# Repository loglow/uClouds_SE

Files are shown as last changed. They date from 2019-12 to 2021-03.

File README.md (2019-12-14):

# µClouds SE (uClouds, microClouds) Eurorack [Rev D]

## 8HP Eurorack module | Granular audio processor

[μClouds SE](http://uclouds-se.com) is a granular audio processor that creates textures and soundscapes by combining multiple segments of sound taken from a recording buffer.

This re-engineered Eurorack module updates and simplifies the classic [Mutable Instruments Clouds](https://mutable-instruments.net/modules/clouds/) design by miniaturizing the module from 18HP to 8HP and redesigning the front panel layout without eliminating any original functionality.

Fully compatible with upstream Clouds firmware. Includes power cable, mounting hardware, and a one-year warranty. Designed and built with care by [Tall Dog Electronics](http://tall-dog.com) in Western Massachusetts. Licensed [CC BY-SA 4.0](https://creativecommons.org/licenses/by-sa/4.0/) open source hardware.

- **Height:** 3U (128.5 mm)
- **Width:** 8HP (40.3 mm)
- **Depth:** 43 mm (with power)
- **+12V:** 120 mA (average)
- **-12V:** 10 mA (average)

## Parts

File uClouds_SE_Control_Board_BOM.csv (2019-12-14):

Reference | Quantity | Description | Manufacturer | Part Number | Digi-Key P/N
D1 D2 D3 D4 | 4 | LED GRN/RED DIFF 3MM ROUND T/H | Kingbright | WP3VEGW | 754-1221-ND
DS1 DS2 DS3 DS4 | 4 | LED SPACER 3MM T-1 BLACK 8MM | Essentra | LEDM-2-08 | RPC4261-ND
H1 H2 H3 H4 | 4 | CONN HEADER 10POS .100 STR 15AU | Amphenol FCI | 67997-210HLF | 609-3236-ND
J1 J2 J3 J4 J5 J6 J7 J8 J9 J10 J11 J12 | 12 | 3.5MM JACK VERTICAL PCB MOUNT | Wenzhou QingPu | WQP-PJ398SM | N/A
P1 P2 P4 P5 P6 P7 | 6 | POT 9MM LINEAR B10K | Song Huei | R0904N-B10K,L-25KQ/LWS | N/A
P3 | 1 | POT 9MM AUDIO A50K DUAL GANG | Song Huei | RK1109G-A50K,L-25KC | N/A
S1 | 1 | SWITCH TACTILE SPST-NO 0.05A 12V | E-Switch | TL1265GQSCLR | EG4967-ND
S2 S3 | 2 | SWITCH TACTILE SPST-NO 0.05A 12V | E-Switch | TL1105DF160Q | EG1865-ND

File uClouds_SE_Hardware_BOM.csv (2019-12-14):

Description | Quantity
Button Shim, FR-4, Black, 1.2 mm | 1
Micro Knob, T18 Shaft, Black | 1
Thonkiconn Knurled Nut, Steel, M6 | 12
Threaded Hex Standoff, Brass, M2.5 x 11 mm | 2
Standoff Screw, Button Head, Hex Socket, M2.5 x 6 mm | 4

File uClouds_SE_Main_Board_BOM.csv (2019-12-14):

Reference | Quantity | Description | Manufacturer | Part Number | Digi-Key P/N
C1 C7 C9 C11 C13 C14 C17 C18 C19 C20 C24 C32 C33 C34 C35 C36 C47 C49 C50 C53 C55 | 21 | CAP CER 0.1UF 16V X7R 0603 | Samsung | CL10B104KO8NNWC | 1276-1939-1-ND
C2 C4 C15 C21 C26 C27 C41 C42 C43 | 9 | CAP 10 UF 20% 25 V | Wurth Electronics | 865230440002 | 732-8259-1-ND
C3 C6 C16 C25 | 4 | CAP CER 1UF 16V X7R 0603 | Samsung | CL10B105MO8NNWC | 1276-6524-1-ND
C5 C10 | 2 | CAP CER 2.2UF 10V X7R 0603 | Samsung | CL10B225KP8NNNC | 1276-1134-1-ND
C8 C12 C22 C23 C28 C37 | 6 | CAP CER 18PF 50V C0G/NP0 0603 | Samsung | CL10C180FB8NNNC | 1276-2206-1-ND
C29 C30 C31 C38 C39 C40 | 6 | CAP CER 1000PF 50V C0G/NP0 0603 | Samsung | CL10C102JB8NNNC | 1276-1091-1-ND
C44 C48 C51 C52 C54 | 5 | CAP 47 UF 20% 25 V | Wurth Electronics | 865230445005 | 732-8262-1-ND
C45 C46 | 2 | CAP CER 220PF 50V C0G/NP0 0603 | Samsung | CL10C221JB8NNNC | 1276-1048-1-ND
D1 D2 | 2 | DIODE SCHOTTKY 40V 1A SOD123 | Diodes Incorporated | 1N5819HW-7-F | 1N5819HW-FDICT-ND
H1 H2 H3 H4 | 4 | CONN HEADER FMAL 10PS.1" DL GOLD | Sullins | PPPC052LFBN-RC | S7108-ND
H5 | 1 | BOX HEADER, 0.050 10 POS | CNC Tech | 3220-10-0100-00 | 1175-1627-ND
H7 | 1 | CONN HEADER VERT 10POS GOLD | On Shore Technology | 302-S101 | ED1543-ND
Q1 Q2 | 2 | TRANS NPN 40V 0.2A SMD SOT23-3 | Diodes Incorporated | MMBT3904-7-F | MMBT3904-FDICT-ND
R1 R13 R21 | 3 | RES SMD 10K OHM 1% 1/10W 0603 | Panasonic | ERJ-3EKF1002V | P10.0KHCT-ND
R2 R3 | 2 | RES SMD 100 OHM 1% 1/10W 0603 | Panasonic | ERJ-3EKF1000V | P100HCT-ND
R4 R5 | 2 | RES SMD 2.2K OHM 1% 1/10W 0603 | Panasonic | ERJ-3EKF2201V | P2.20KHCT-ND
R6 R7 R8 R12 R20 R42 R43 R44 | 8 | RES SMD 100K OHM 0.1% 1/10W 0603 | Susumu | RG1608P-104-B-T5 | RG16P100KBCT-ND
R9 R11 R32 R33 R34 | 5 | RES SMD 200K OHM 0.1% 1/10W 0603 | Susumu | RG1608P-204-B-T5 | RG16P200KBCT-ND
R10 | 1 | RES SMD 180K OHM 0.1% 1/10W 0603 | Susumu | RG1608P-184-B-T5 | RG16P180KBCT-ND
R14 R28 R29 | 3 | RES SMD 33K OHM 0.1% 1/10W 0603 | Susumu | RG1608P-333-B-T5 | RG16P33.0KBCT-ND
R15 | 1 | RES SMD 47K OHM 0.1% 1/10W 0603 | Susumu | RG1608P-473-B-T5 | RG16P47.0KBCT-ND
R16 R30 | 2 | RES SMD 66.5KOHM 0.1% 1/10W 0603 | Panasonic | ERA-3AEB6652V | P66.5KDBCT-ND
R17 R26 R46 R47 R48 R49 | 6 | RES SMD 5.6K OHM 0.1% 1/10W 0603 | Susumu | RG1608P-562-B-T5 | RG16P5.6KBCT-ND
R18 R19 R25 R27 | 4 | RES SMD 39K OHM 0.1% 1/10W 0603 | Susumu | RG1608P-393-B-T5 | RG16P39.0KBCT-ND
R22 R23 | 2 | RES SMD 1K OHM 0.1% 1/10W 0603 | Susumu | RG1608P-102-B-T5 | RG16P1.0KBCT-ND
R24 R35 R36 R37 R38 R39 R40 R41 | 8 | RES SMD 68 OHM 1% 1/10W 0603 | Panasonic | ERJ-3EKF68R0V | P68.0HCT-ND
R31 R54 | 2 | RES SMD 470 OHM 1% 1/10W 0603 | Panasonic | ERJ-3EKF4700V | P470HCT-ND
R45 | 1 | RES SMD 4.7 OHM 5% 1/4W 1206 | Panasonic | ERJ-8GEYJ4R7V | P4.7ECT-ND
R50 R53 | 2 | RES SMD 22K OHM 0.1% 1/10W 0603 | Susumu | RG1608P-223-B-T5 | RG16P22.0KBCT-ND
R51 R52 | 2 | RES SMD 3.3K OHM 0.1% 1/10W 0603 | Susumu | RG1608P-332-B-T5 | RG16P3.3KBCT-ND
U1 | 1 | IC CODEC PORT INTERNET 28SSOP | Cirrus Logic | WM8731SEDS/RV | WM8731SEDS/RVCT-ND
U2 | 1 | IC MCU 32BIT 1MB FLASH 64LQFP | STMicroelectronics | STM32F405RGT6 | 497-11767-ND
U3 U7 | 2 | IC OPAMP JFET 3MHZ 8TSSOP | Texas Instruments | TL072CPWR | 296-7193-1-ND
U4 | 1 | IC OPAMP GP 1MHZ RRO 14TSSOP | Microchip Technology | MCP6004T-E/ST | MCP6004T-E/STCT-ND
U5 | 1 | IC OPAMP GP 1MHZ RRO 8MSOP | Microchip Technology | MCP6002T-I/MS | MCP6002T-I/MSCT-ND
U6 | 1 | IC 8BIT SHIFT REGISTER 16-TSSOP | Texas Instruments | SN74HC595PWR | 296-23258-1-ND
U8 U9 | 2 | IC REG LINEAR 3.3V 800MA SOT223 | Texas Instruments | LM1117IMP-3.3/NOPB | LM1117IMP-3.3/NOPBCT-ND
U10 | 1 | IC VREF SHUNT 10V SOT23-3 | Texas Instruments | LM4040C10IDBZR | 296-20882-1-ND
X1 | 1 | CRYSTAL 12.2880MHZ 18PF SMD | Abracon | ABM3-12.288MHZ-D2Y-T | 535-10635-1-ND
X2 | 1 | CRYSTAL 8.0000MHZ 18PF SMD | Abracon | ABM3-8.000MHZ-D2Y-T | 535-10630-1-ND

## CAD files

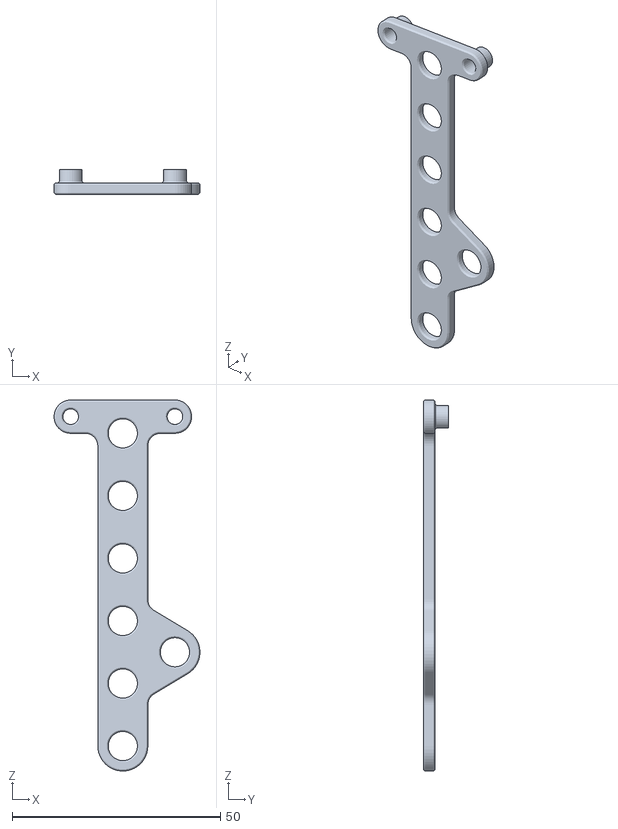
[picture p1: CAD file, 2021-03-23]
uClouds_SE_Assembly_Spacer.stl
35.0 x 6.00 x 89.0

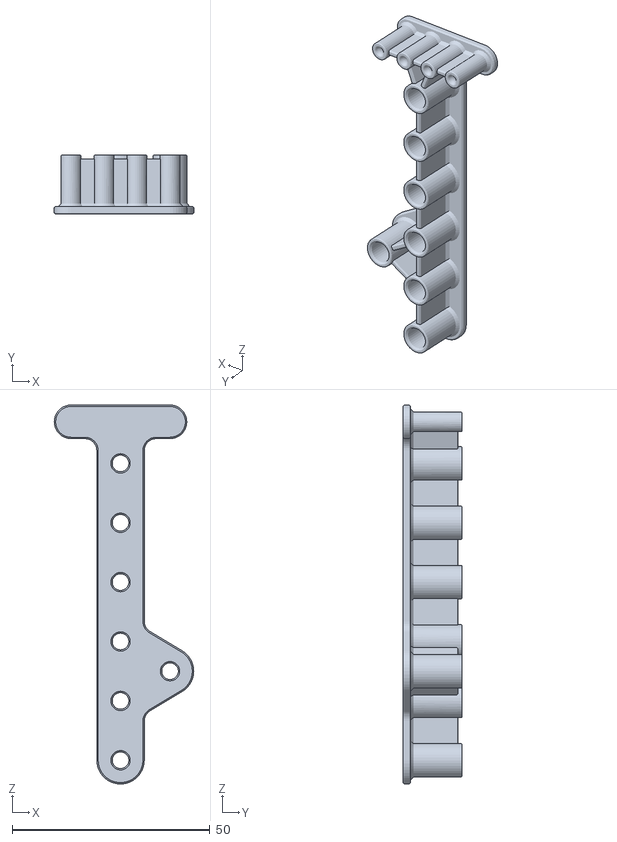
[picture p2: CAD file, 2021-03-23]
uClouds_SE_Assembly_Cap.stl
35.2 x 15.0 x 95.8

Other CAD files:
uClouds_SE_Model.skp

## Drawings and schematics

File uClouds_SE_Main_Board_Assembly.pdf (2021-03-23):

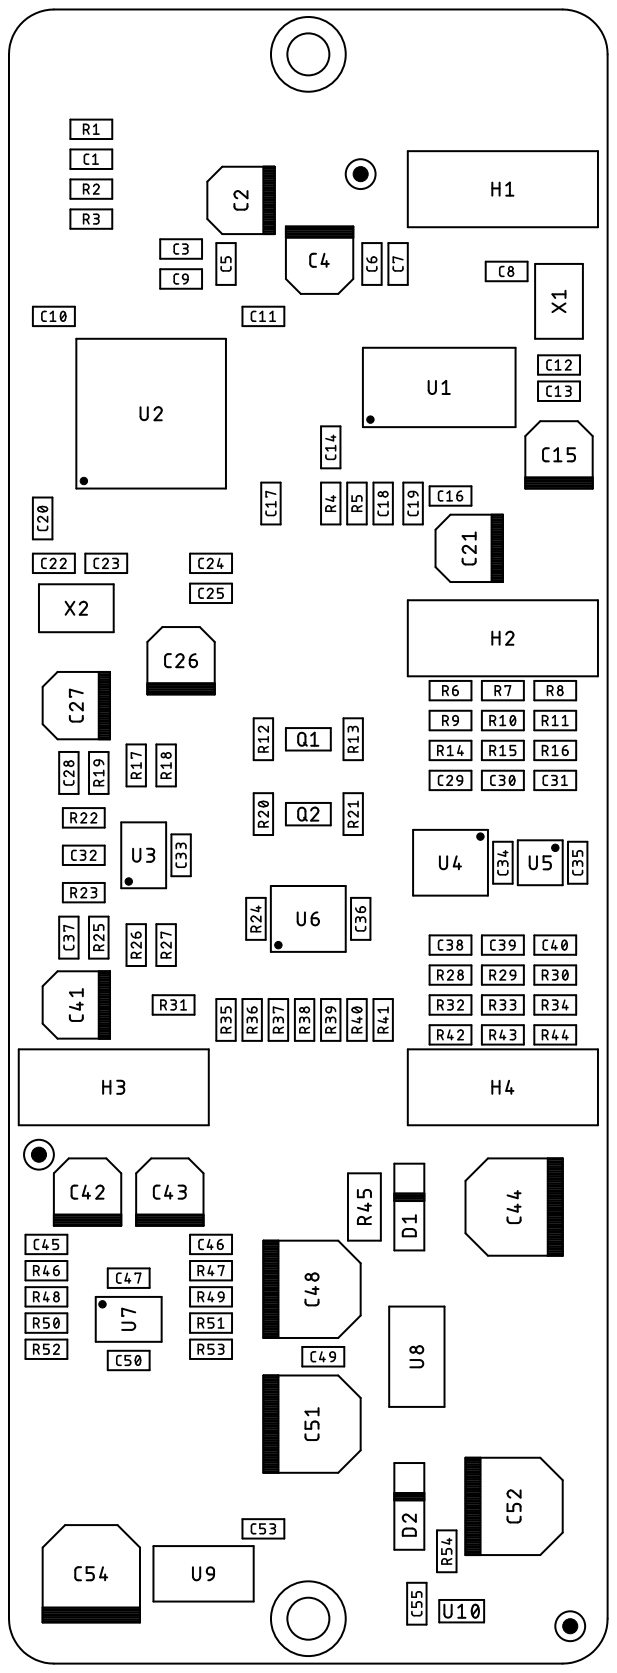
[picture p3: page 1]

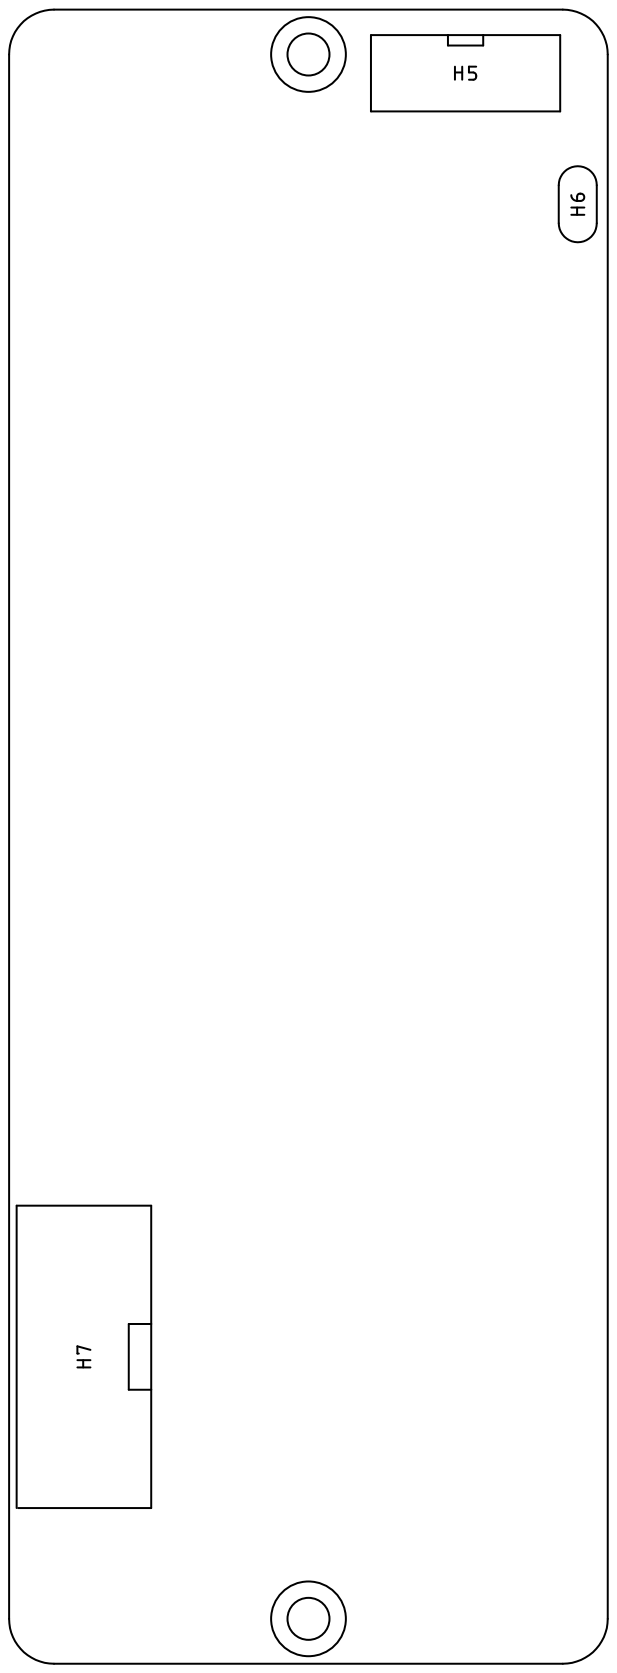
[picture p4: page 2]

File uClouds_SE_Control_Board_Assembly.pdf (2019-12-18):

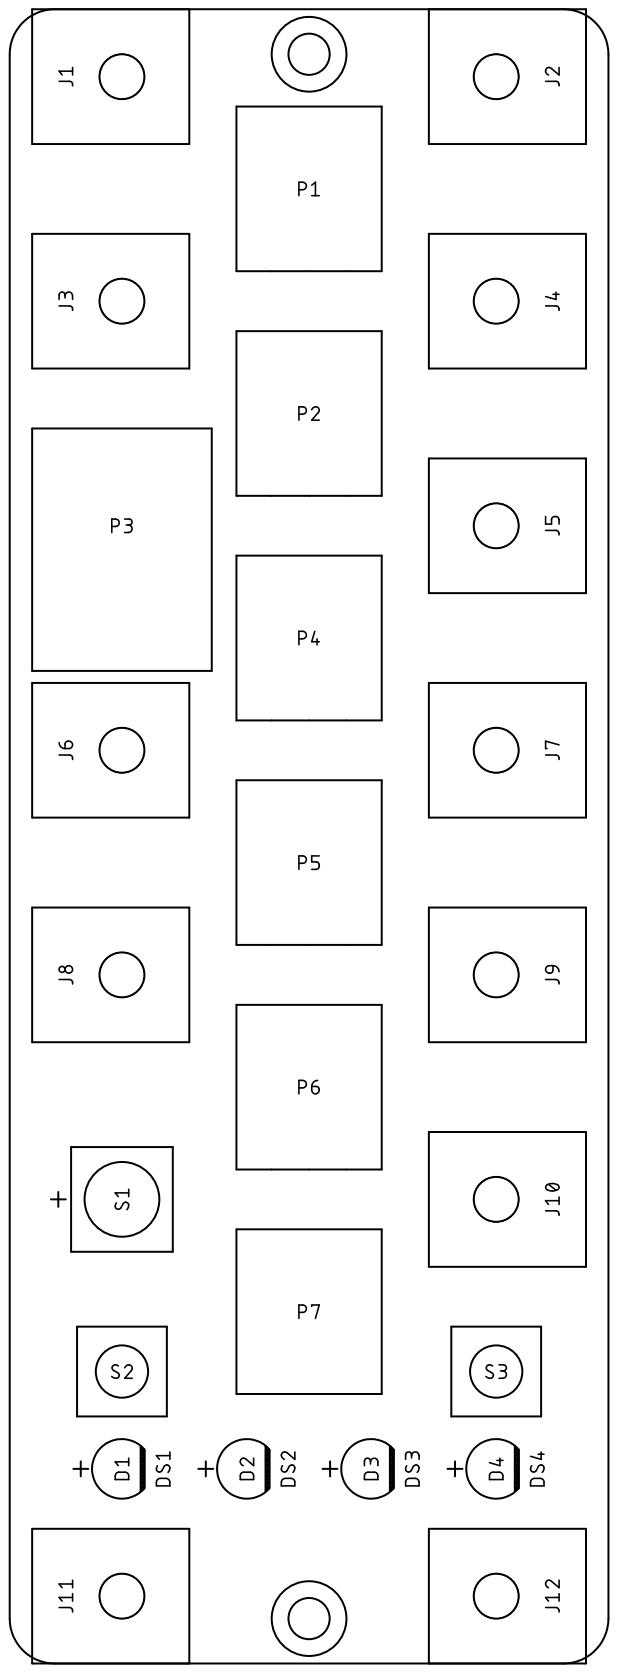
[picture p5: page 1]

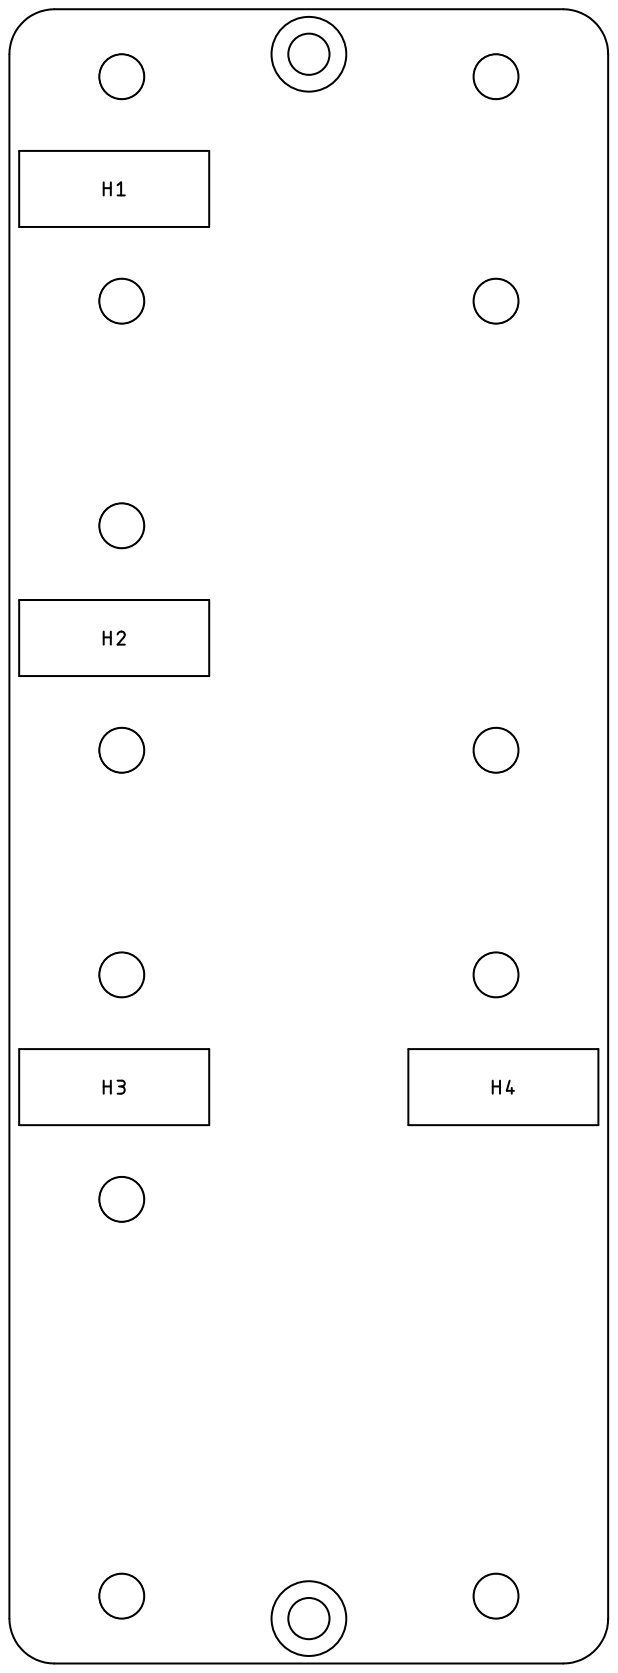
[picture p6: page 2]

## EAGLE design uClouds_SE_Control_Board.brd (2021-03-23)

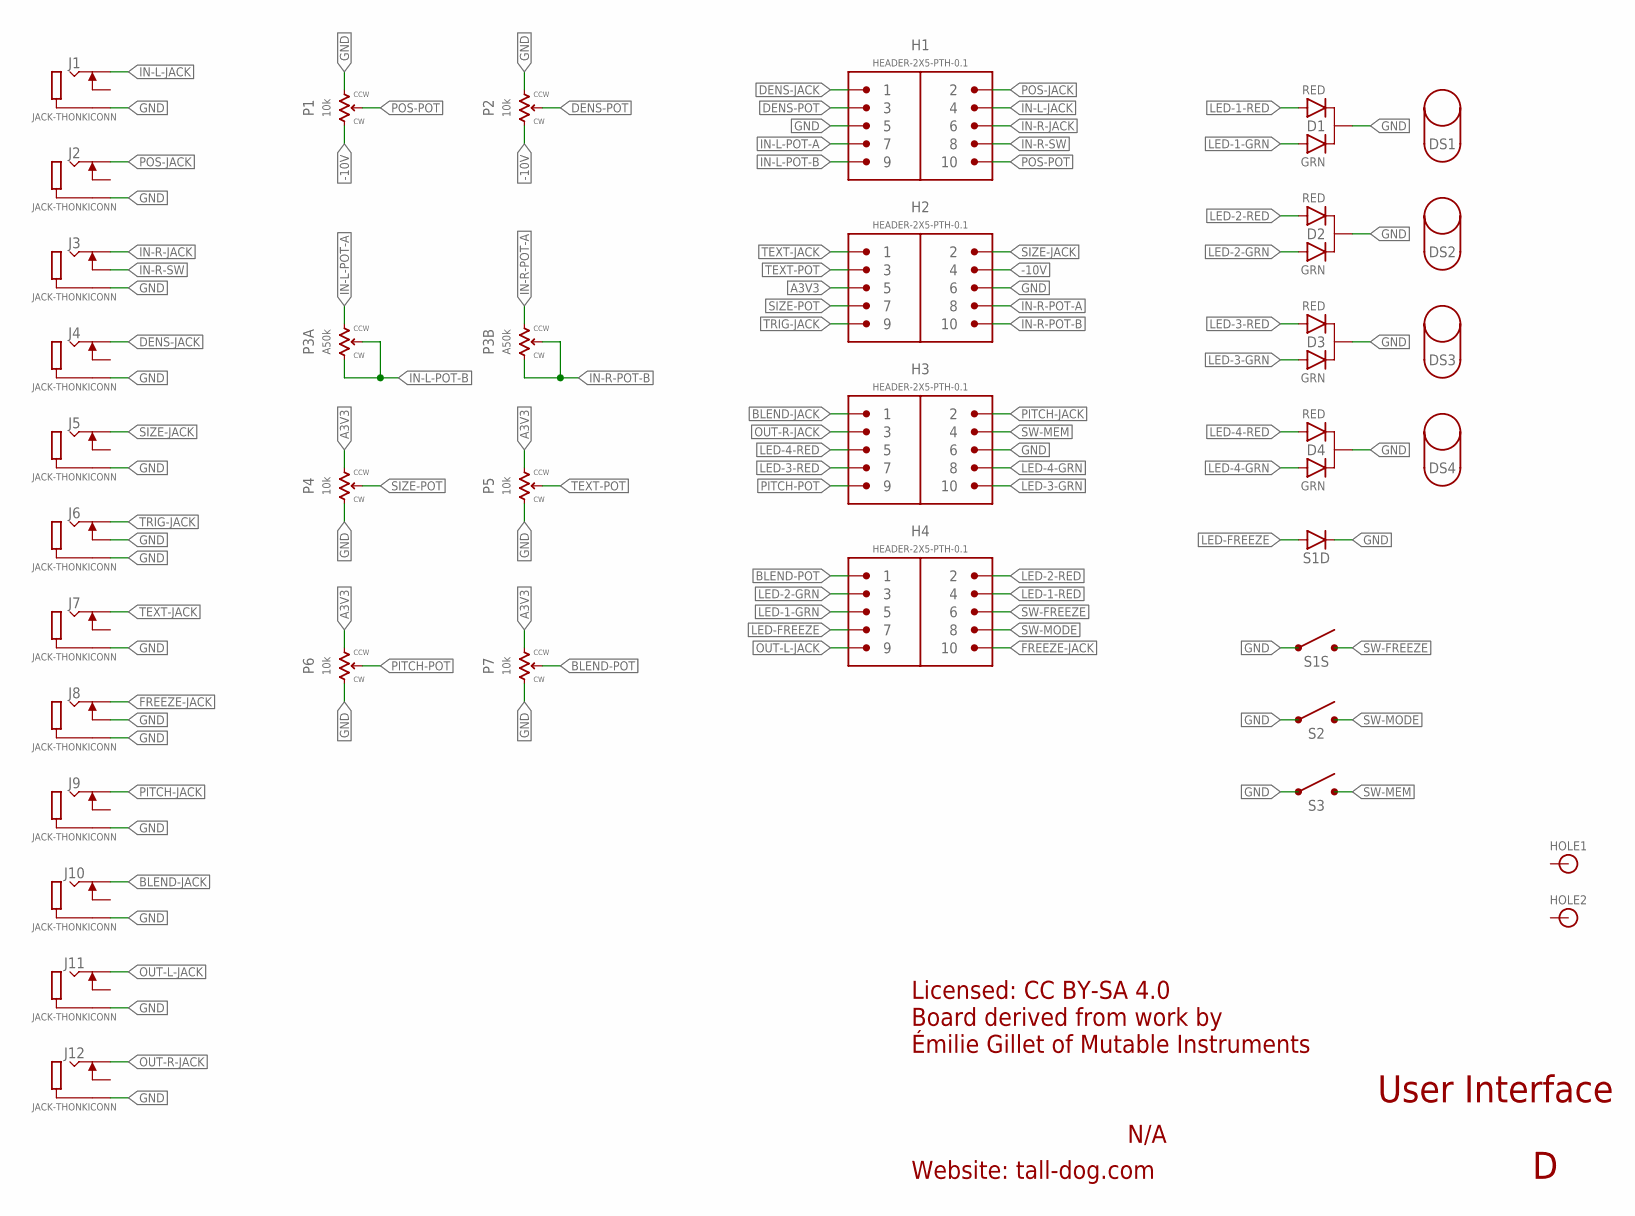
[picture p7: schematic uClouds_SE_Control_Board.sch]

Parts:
D1, D2, D3, D4: LED-DUAL-PTH; LED-T1-3
DS1, DS2, DS3, DS4: LED-SPACER
H1, H2, H3, H4: HEADER-2X5-PTH-0.1; PTH-0.1-2X5-MALE
HOLE1, HOLE2: HOLE; M2.5-HOLE
J1, J2, J3, J4, J5, J6, J7, J8, J9, J10, J11, J12: JACK-THONKICONN; THONKICONN
P1, P2, P4, P5, P6, P7: 10k; POT-R0904N
P3: A50k; POT-RK1109G
S1: SPST-LED; TL1265
S2, S3: SPST-PTH; TL1105

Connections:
-10V: H2.4, P1.P$3 (3), P2.P$3 (3)
A3V3: H2.5, P4.P$1 (1), P5.P$1 (1), P6.P$1 (1), P7.P$1 (1)
BLEND-JACK: H3.1, J10.P3 (3)
BLEND-POT: H4.1, P7.P$2 (2)
DENS-JACK: H1.1, J4.P3 (3)
DENS-POT: H1.3, P2.P$2 (2)
FREEZE-JACK: H4.10, J8.P3 (3)
GND: D1.2 (C), D2.2 (C), D3.2 (C), D4.2 (C), H1.5, H2.6, H3.6, J1.P1 (1), J2.P1 (1), J3.P1 (1), J4.P1 (1), J5.P1 (1), J6.P1 (1), J6.P2 (2), J7.P1 (1), J8.P1 (1), J8.P2 (2), J9.P1 (1), J10.P1 (1), J11.P1 (1), J12.P1 (1), P1.P$1 (1), P2.P$1 (1), P4.P$3 (3), P5.P$3 (3), P6.P$3 (3), P7.P$3 (3), S1.1, S1.2 (1), S1.5 (C), S2.1, S2.2 (1), S3.1, S3.2 (1)
IN-L-JACK: H1.4, J1.P3 (3)
IN-L-POT-A: H1.7, P3.1
IN-L-POT-B: H1.9, P3.2, P3.3
IN-R-JACK: H1.6, J3.P3 (3)
IN-R-POT-A: H2.8, P3.1' (1)
IN-R-POT-B: H2.10, P3.2' (2), P3.3' (3)
IN-R-SW: H1.8, J3.P2 (2)
LED-1-GRN: D1.3 (GRN), H4.5
LED-1-RED: D1.1 (RED), H4.4
LED-2-GRN: D2.3 (GRN), H4.3
LED-2-RED: D2.1 (RED), H4.2
LED-3-GRN: D3.3 (GRN), H3.10
LED-3-RED: D3.1 (RED), H3.7
LED-4-GRN: D4.3 (GRN), H3.8
LED-4-RED: D4.1 (RED), H3.5
LED-FREEZE: H4.7, S1.6 (A)
OUT-L-JACK: H4.9, J11.P3 (3)
OUT-R-JACK: H3.3, J12.P3 (3)
PITCH-JACK: H3.2, J9.P3 (3)
PITCH-POT: H3.9, P6.P$2 (2)
POS-JACK: H1.2, J2.P3 (3)
POS-POT: H1.10, P1.P$2 (2)
SIZE-JACK: H2.2, J5.P3 (3)
SIZE-POT: H2.7, P4.P$2 (2)
SW-FREEZE: H4.6, S1.3 (2), S1.4 (2)
SW-MEM: H3.4, S3.3 (2), S3.4 (2)
SW-MODE: H4.8, S2.3 (2), S2.4 (2)
TEXT-JACK: H2.1, J7.P3 (3)
TEXT-POT: H2.3, P5.P$2 (2)
TRIG-JACK: H2.9, J6.P3 (3)

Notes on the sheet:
Licensed: CC BY-SA 4.0 Board derived from work by Émilie Gillet of Mutable Instruments
Website: tall-dog.com
N/A
User Interface

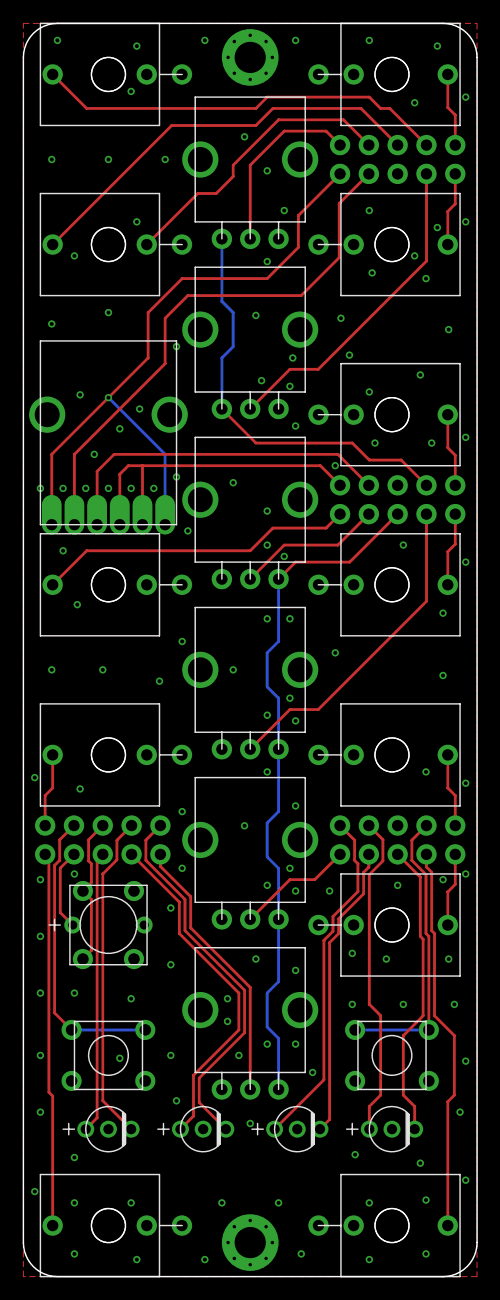
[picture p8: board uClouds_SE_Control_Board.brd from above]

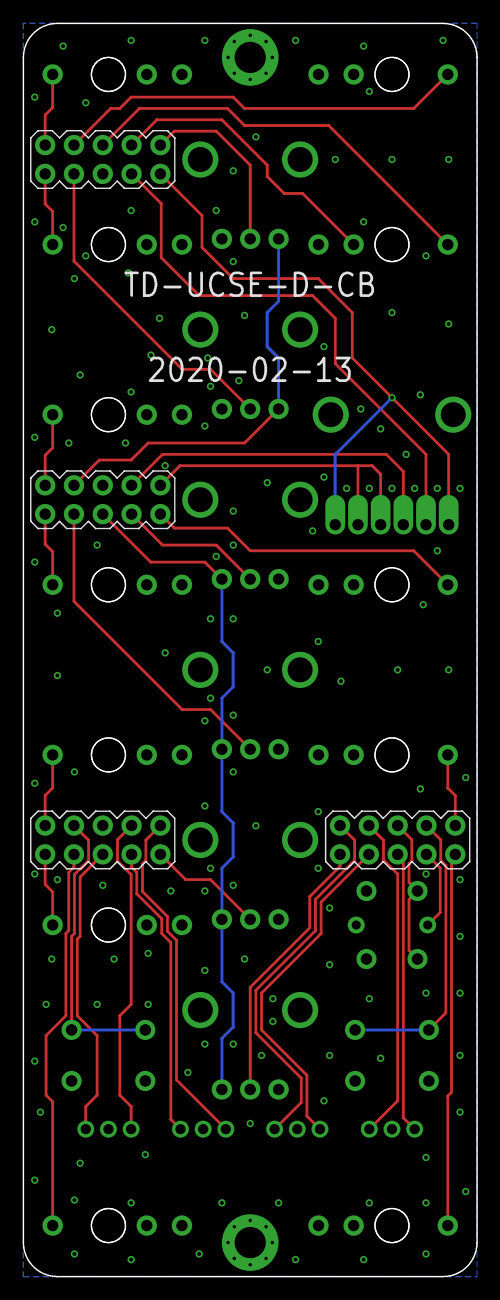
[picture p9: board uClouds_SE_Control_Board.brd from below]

Board: 2 copper layers, 40.0 x 110.5 mm, 36 parts (4 on the bottom side), 38 nets.

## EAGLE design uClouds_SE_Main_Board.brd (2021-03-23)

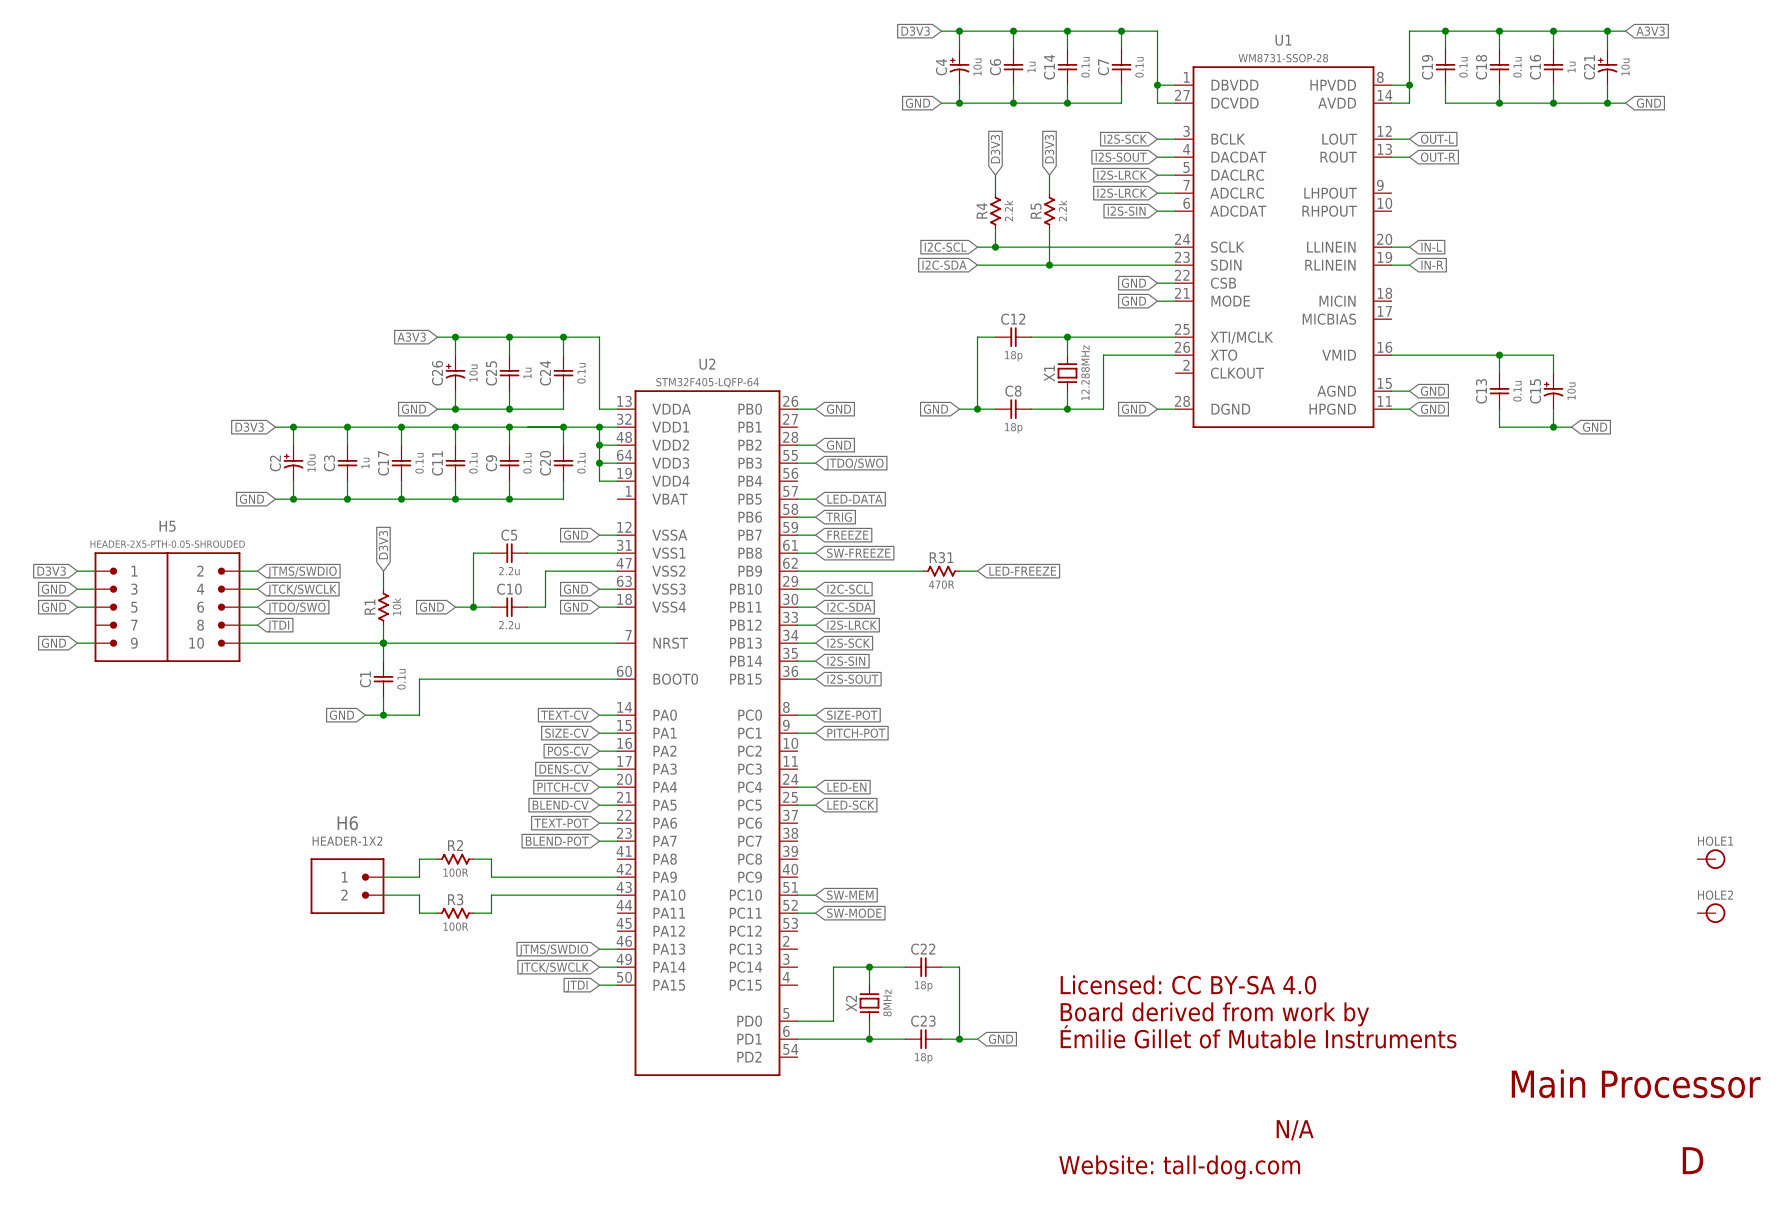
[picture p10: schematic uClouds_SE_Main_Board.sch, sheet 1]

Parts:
C1, C7, C9, C11, C13, C14, C17, C18, C19, C20, C24: 0.1u; 0603-NP
C2, C4, C15, C21, C26: 10u; ELECTRO-SMD-4.3MM
C3, C6, C16, C25: 1u; 0603-NP
C5, C10: 2.2u; 0603-NP
C8, C12, C22, C23: 18p; 0603-NP
H5: HEADER-2X5-PTH-0.05-SHROUDED; PTH-0.05-2X5-SHROUDED
H6: HEADER-1X2; PTH-0.1-1X2
HOLE1, HOLE2: HOLE; M2.5-HOLE
R1: 10k; 0603-NP
R2, R3: 100R; 0603-NP
R4, R5: 2.2k; 0603-NP
R31: 470R; 0603-NP
U1: WM8731-SSOP-28; SSOP-28
U2: STM32F405-LQFP-64; LQFP-64
X1: 12.288MHz; CRYSTAL-ABM3
X2: 8MHz; CRYSTAL-ABM3

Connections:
A3V3: C16.2, C18.2, C19.2, C21.A (POS), C24.2, C25.2, C26.A (POS), U1.8 (HPVDD), U1.14 (AVDD), U2.13 (VDDA); also elsewhere on the board
BLEND-CV: U2.21 (PA5); also elsewhere on the board
BLEND-POT: U2.23 (PA7); also elsewhere on the board
D3V3: C2.A (POS), C3.2, C4.A (POS), C6.2, C7.2, C9.2, C11.2, C14.2, C17.2, C20.2, H5.1, R1.2, R4.2, R5.2, U1.1 (DBVDD), U1.27 (DCVDD), U2.19 (VDD4), U2.32 (VDD1), U2.48 (VDD2), U2.64 (VDD3); also elsewhere on the board
DENS-CV: U2.17 (PA3); also elsewhere on the board
FREEZE: U2.59 (PB7); also elsewhere on the board
GND: C1.1, C2.C (NEG), C3.1, C4.C (NEG), C5.1, C6.1, C7.1, C8.1, C9.1, C10.1, C11.1, C12.1, C13.1, C14.1, C15.C (NEG), C16.1, C17.1, C18.1, C19.1, C20.1, C21.C (NEG), C22.2, C23.2, C24.1, C25.1, C26.C (NEG), H5.3, H5.5, H5.9, U1.11 (HPGND), U1.15 (AGND), U1.21 (MODE), U1.22 (CSB), U1.28 (DGND), U2.12 (VSSA), U2.18 (VSS4), U2.26 (PB0), U2.28 (PB2), U2.60 (BOOT0), U2.63 (VSS3); also elsewhere on the board
I2C-SCL: R4.1, U1.24 (SCLK), U2.29 (PB10)
I2C-SDA: R5.1, U1.23 (SDIN), U2.30 (PB11)
I2S-LRCK: U1.5 (DACLRC), U1.7 (ADCLRC), U2.33 (PB12)
I2S-SCK: U1.3 (BCLK), U2.34 (PB13)
I2S-SIN: U1.6 (ADCDAT), U2.35 (PB14)
I2S-SOUT: U1.4 (DACDAT), U2.36 (PB15)
IN-L: U1.20 (LLINEIN); also elsewhere on the board
IN-R: U1.19 (RLINEIN); also elsewhere on the board
JTCK/SWCLK: H5.4, U2.49 (PA14)
JTDI: H5.8, U2.50 (PA15)
JTDO/SWO: H5.6, U2.55 (PB3)
JTMS/SWDIO: H5.2, U2.46 (PA13)
LED-DATA: U2.57 (PB5); also elsewhere on the board
LED-EN: U2.24 (PC4); also elsewhere on the board
LED-FREEZE: R31.2; also elsewhere on the board
LED-SCK: U2.25 (PC5); also elsewhere on the board
unnamed: C5.2, U2.31 (VSS1)
unnamed: C10.2, U2.47 (VSS2)
unnamed: C22.1, U2.5 (PD0), X2.2
unnamed: C23.1, U2.6 (PD1), X2.1
unnamed: C12.2, U1.25 (XTI/MCLK), X1.2
unnamed: C8.2, U1.26 (XTO), X1.1
unnamed: C13.2, C15.A (POS), U1.16 (VMID)
unnamed: R31.1, U2.62 (PB9)
OUT-L: U1.12 (LOUT); also elsewhere on the board
OUT-R: U1.13 (ROUT); also elsewhere on the board
PITCH-CV: U2.20 (PA4); also elsewhere on the board
PITCH-POT: U2.9 (PC1); also elsewhere on the board
POS-CV: U2.16 (PA2); also elsewhere on the board
RESET: C1.2, H5.10, R1.1, U2.7 (NRST)
RX: H6.2, R3.1
RX1: R3.2, U2.43 (PA10)
SIZE-CV: U2.15 (PA1); also elsewhere on the board
SIZE-POT: U2.8 (PC0); also elsewhere on the board
SW-FREEZE: U2.61 (PB8); also elsewhere on the board
SW-MEM: U2.51 (PC10); also elsewhere on the board
SW-MODE: U2.52 (PC11); also elsewhere on the board
TEXT-CV: U2.14 (PA0); also elsewhere on the board
TEXT-POT: U2.22 (PA6); also elsewhere on the board
TRIG: U2.58 (PB6); also elsewhere on the board
TX: H6.1, R2.1
TX1: R2.2, U2.42 (PA9)

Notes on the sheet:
Licensed: CC BY-SA 4.0 Board derived from work by Émilie Gillet of Mutable Instruments
Website: tall-dog.com
N/A
Main Processor

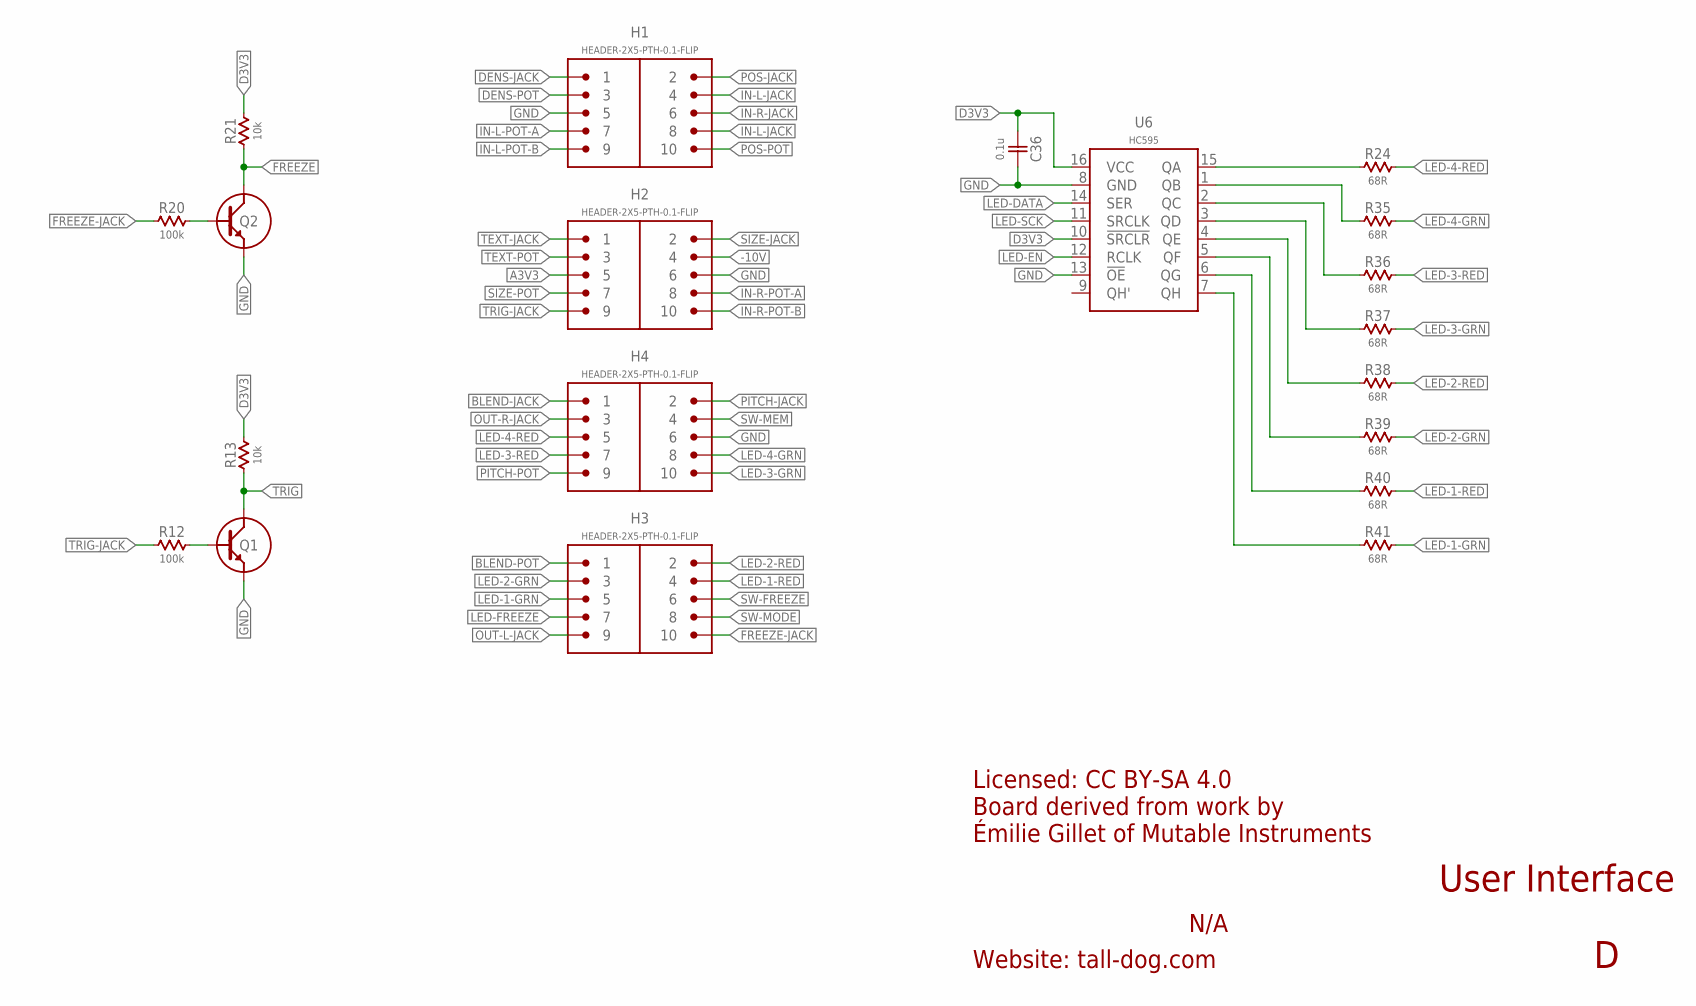
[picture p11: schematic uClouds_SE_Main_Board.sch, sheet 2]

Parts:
C36: 0.1u; 0603-NP
H1, H2, H3, H4: HEADER-2X5-PTH-0.1-FLIP; PTH-0.1-2X5-FEMALE
Q1, Q2: NPN-SOT23-BEC; SOT-23
R12, R20: 100k; 0603-NP
R13, R21: 10k; 0603-NP
R24, R35, R36, R37, R38, R39, R40, R41: 68R; 0603-NP
U6: HC595; TSSOP-16

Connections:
-10V: H2.4; also elsewhere on the board
A3V3: H2.5; also elsewhere on the board
BLEND-JACK: H4.1; also elsewhere on the board
BLEND-POT: H3.1; also elsewhere on the board
D3V3: C36.2, R13.2, R21.2, U6.10 (!SRCLR), U6.16 (VCC); also elsewhere on the board
DENS-JACK: H1.1; also elsewhere on the board
DENS-POT: H1.3; also elsewhere on the board
FREEZE: Q2.3 (C), R21.1; also elsewhere on the board
FREEZE-JACK: H3.10, R20.1
GND: C36.1, H1.5, H2.6, H4.6, Q1.2 (E), Q2.2 (E), U6.8 (GND), U6.13 (!OE); also elsewhere on the board
IN-L-JACK: H1.4, H1.8; also elsewhere on the board
IN-L-POT-A: H1.7; also elsewhere on the board
IN-L-POT-B: H1.9; also elsewhere on the board
IN-R-JACK: H1.6; also elsewhere on the board
IN-R-POT-A: H2.8; also elsewhere on the board
IN-R-POT-B: H2.10; also elsewhere on the board
LED-1-GRN: H3.5, R41.2
LED-1-RED: H3.4, R40.2
LED-2-GRN: H3.3, R39.2
LED-2-RED: H3.2, R38.2
LED-3-GRN: H4.10, R37.2
LED-3-RED: H4.7, R36.2
LED-4-GRN: H4.8, R35.2
LED-4-RED: H4.5, R24.2
LED-DATA: U6.14 (SER); also elsewhere on the board
LED-EN: U6.12 (RCLK); also elsewhere on the board
LED-FREEZE: H3.7; also elsewhere on the board
LED-SCK: U6.11 (SRCLK); also elsewhere on the board
unnamed: R24.1, U6.15 (QA)
unnamed: R35.1, U6.1 (QB)
unnamed: R36.1, U6.2 (QC)
unnamed: Q1.1 (B), R12.2
unnamed: Q2.1 (B), R20.2
unnamed: R37.1, U6.3 (QD)
unnamed: R38.1, U6.4 (QE)
unnamed: R39.1, U6.5 (QF)
unnamed: R40.1, U6.6 (QG)
unnamed: R41.1, U6.7 (QH)
OUT-L-JACK: H3.9; also elsewhere on the board
OUT-R-JACK: H4.3; also elsewhere on the board
PITCH-JACK: H4.2; also elsewhere on the board
PITCH-POT: H4.9; also elsewhere on the board
POS-JACK: H1.2; also elsewhere on the board
POS-POT: H1.10; also elsewhere on the board
SIZE-JACK: H2.2; also elsewhere on the board
SIZE-POT: H2.7; also elsewhere on the board
SW-FREEZE: H3.6; also elsewhere on the board
SW-MEM: H4.4; also elsewhere on the board
SW-MODE: H3.8; also elsewhere on the board
TEXT-JACK: H2.1; also elsewhere on the board
TEXT-POT: H2.3; also elsewhere on the board
TRIG: Q1.3 (C), R13.1; also elsewhere on the board
TRIG-JACK: H2.9, R12.1

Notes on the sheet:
Licensed: CC BY-SA 4.0 Board derived from work by Émilie Gillet of Mutable Instruments
Website: tall-dog.com
N/A
User Interface

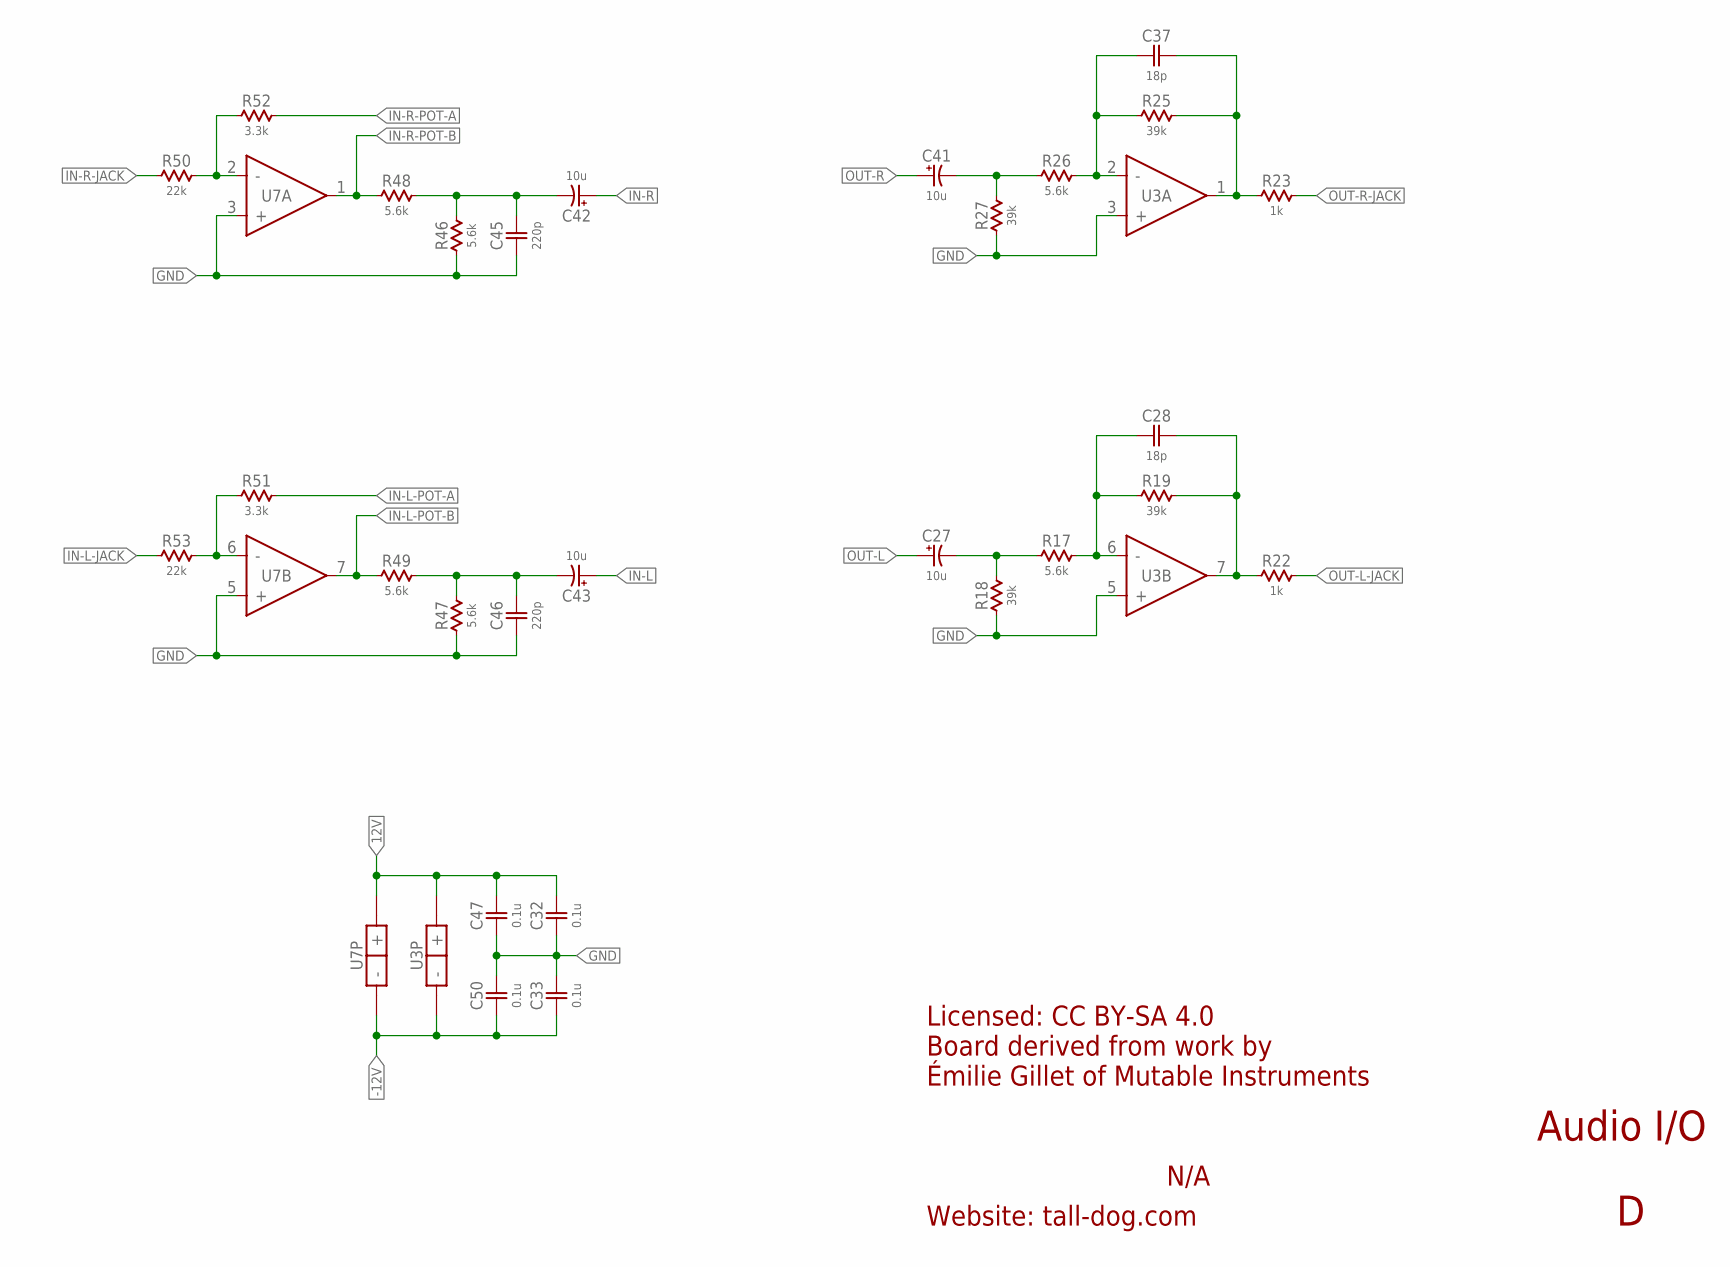
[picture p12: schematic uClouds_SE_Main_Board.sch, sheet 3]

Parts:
C27, C41, C42, C43: 10u; ELECTRO-SMD-4.3MM
C28, C37: 18p; 0603-NP
C32, C33, C47, C50: 0.1u; 0603-NP
C45, C46: 220p; 0603-NP
R17, R26, R46, R47, R48, R49: 5.6k; 0603-NP
R18, R19, R25, R27: 39k; 0603-NP
R22, R23: 1k; 0603-NP
R50, R53: 22k; 0603-NP
R51, R52: 3.3k; 0603-NP
U3, U7: TL072-TSSOP-8; TSSOP-8

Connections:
12V: C32.2, C47.2, U3.8 (+), U7.8 (+); also elsewhere on the board
-12V: C33.1, C50.1, U3.4 (-), U7.4 (-); also elsewhere on the board
GND: C32.1, C33.2, C45.1, C46.1, C47.1, C50.2, R18.1, R27.1, R46.1, R47.1, U3.3 (+), U3.5 (+), U7.3 (+), U7.5 (+); also elsewhere on the board
IN-L: C43.A (POS); also elsewhere on the board
IN-L-JACK: R53.1; also elsewhere on the board
IN-L-POT-A: R51.2; also elsewhere on the board
IN-L-POT-B: R49.1, U7.7 (OUT); also elsewhere on the board
IN-R: C42.A (POS); also elsewhere on the board
IN-R-JACK: R50.1; also elsewhere on the board
IN-R-POT-A: R52.2; also elsewhere on the board
IN-R-POT-B: R48.1, U7.1 (OUT); also elsewhere on the board
unnamed: R50.2, R52.1, U7.2 (-)
unnamed: R51.1, R53.2, U7.6 (-)
unnamed: C27.C (NEG), R17.1, R18.2
unnamed: C43.C (NEG), C46.2, R47.2, R49.2
unnamed: C41.C (NEG), R26.1, R27.2
unnamed: C28.1, R17.2, R19.1, U3.6 (-)
unnamed: C28.2, R19.2, R22.1, U3.7 (OUT)
unnamed: C37.1, R25.1, R26.2, U3.2 (-)
unnamed: C37.2, R23.1, R25.2, U3.1 (OUT)
unnamed: C42.C (NEG), C45.2, R46.2, R48.2
OUT-L: C27.A (POS); also elsewhere on the board
OUT-L-JACK: R22.2; also elsewhere on the board
OUT-R: C41.A (POS); also elsewhere on the board
OUT-R-JACK: R23.2; also elsewhere on the board

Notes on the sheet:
Licensed: CC BY-SA 4.0 Board derived from work by Émilie Gillet of Mutable Instruments
Website: tall-dog.com
N/A
Audio I/O

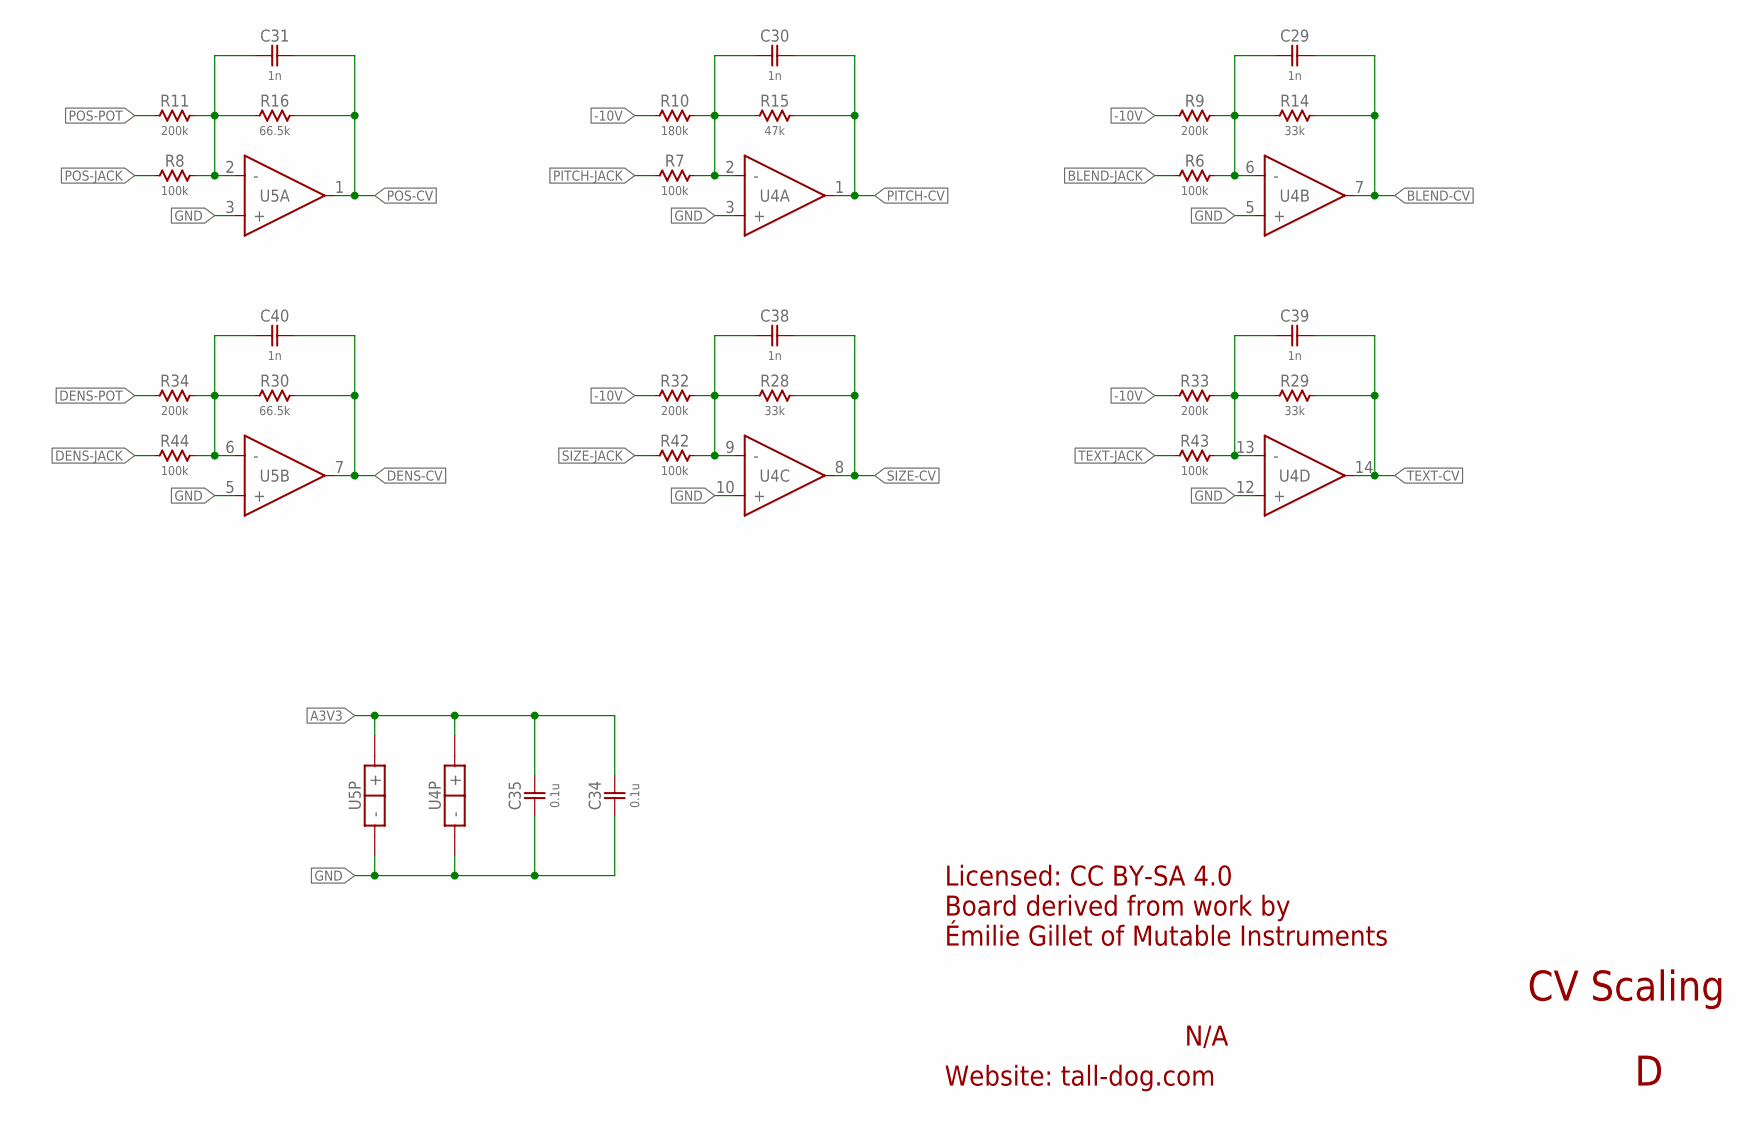
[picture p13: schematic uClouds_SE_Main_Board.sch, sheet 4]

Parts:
C29, C30, C31, C38, C39, C40: 1n; 0603-NP
C34, C35: 0.1u; 0603-NP
R6, R7, R8, R42, R43, R44: 100k; 0603-NP
R9, R11, R32, R33, R34: 200k; 0603-NP
R10: 180k; 0603-NP
R14, R28, R29: 33k; 0603-NP
R15: 47k; 0603-NP
R16, R30: 66.5k; 0603-NP
U4: MCP6004-TSSOP-14; TSSOP-14
U5: MCP6002-MSOP-8; MSOP-8

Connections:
-10V: R9.1, R10.1, R32.1, R33.1; also elsewhere on the board
A3V3: C34.2, C35.2, U4.4 (+), U5.8 (+); also elsewhere on the board
BLEND-CV: C29.2, R14.2, U4.7 (OUT); also elsewhere on the board
BLEND-JACK: R6.1; also elsewhere on the board
DENS-CV: C40.2, R30.2, U5.7 (OUT); also elsewhere on the board
DENS-JACK: R44.1; also elsewhere on the board
DENS-POT: R34.1; also elsewhere on the board
GND: C34.1, C35.1, U4.3 (+), U4.5 (+), U4.10 (+), U4.11 (-), U4.12 (+), U5.3 (+), U5.4 (-), U5.5 (+); also elsewhere on the board
unnamed: C29.1, R6.2, R9.2, R14.1, U4.6 (-)
unnamed: C31.1, R8.2, R11.2, R16.1, U5.2 (-)
unnamed: C40.1, R30.1, R34.2, R44.2, U5.6 (-)
unnamed: C38.1, R28.1, R32.2, R42.2, U4.9 (-)
unnamed: C30.1, R7.2, R10.2, R15.1, U4.2 (-)
unnamed: C39.1, R29.1, R33.2, R43.2, U4.13 (-)
PITCH-CV: C30.2, R15.2, U4.1 (OUT); also elsewhere on the board
PITCH-JACK: R7.1; also elsewhere on the board
POS-CV: C31.2, R16.2, U5.1 (OUT); also elsewhere on the board
POS-JACK: R8.1; also elsewhere on the board
POS-POT: R11.1; also elsewhere on the board
SIZE-CV: C38.2, R28.2, U4.8 (OUT); also elsewhere on the board
SIZE-JACK: R42.1; also elsewhere on the board
TEXT-CV: C39.2, R29.2, U4.14 (OUT); also elsewhere on the board
TEXT-JACK: R43.1; also elsewhere on the board

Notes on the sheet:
Licensed: CC BY-SA 4.0 Board derived from work by Émilie Gillet of Mutable Instruments
Website: tall-dog.com
N/A
CV Scaling

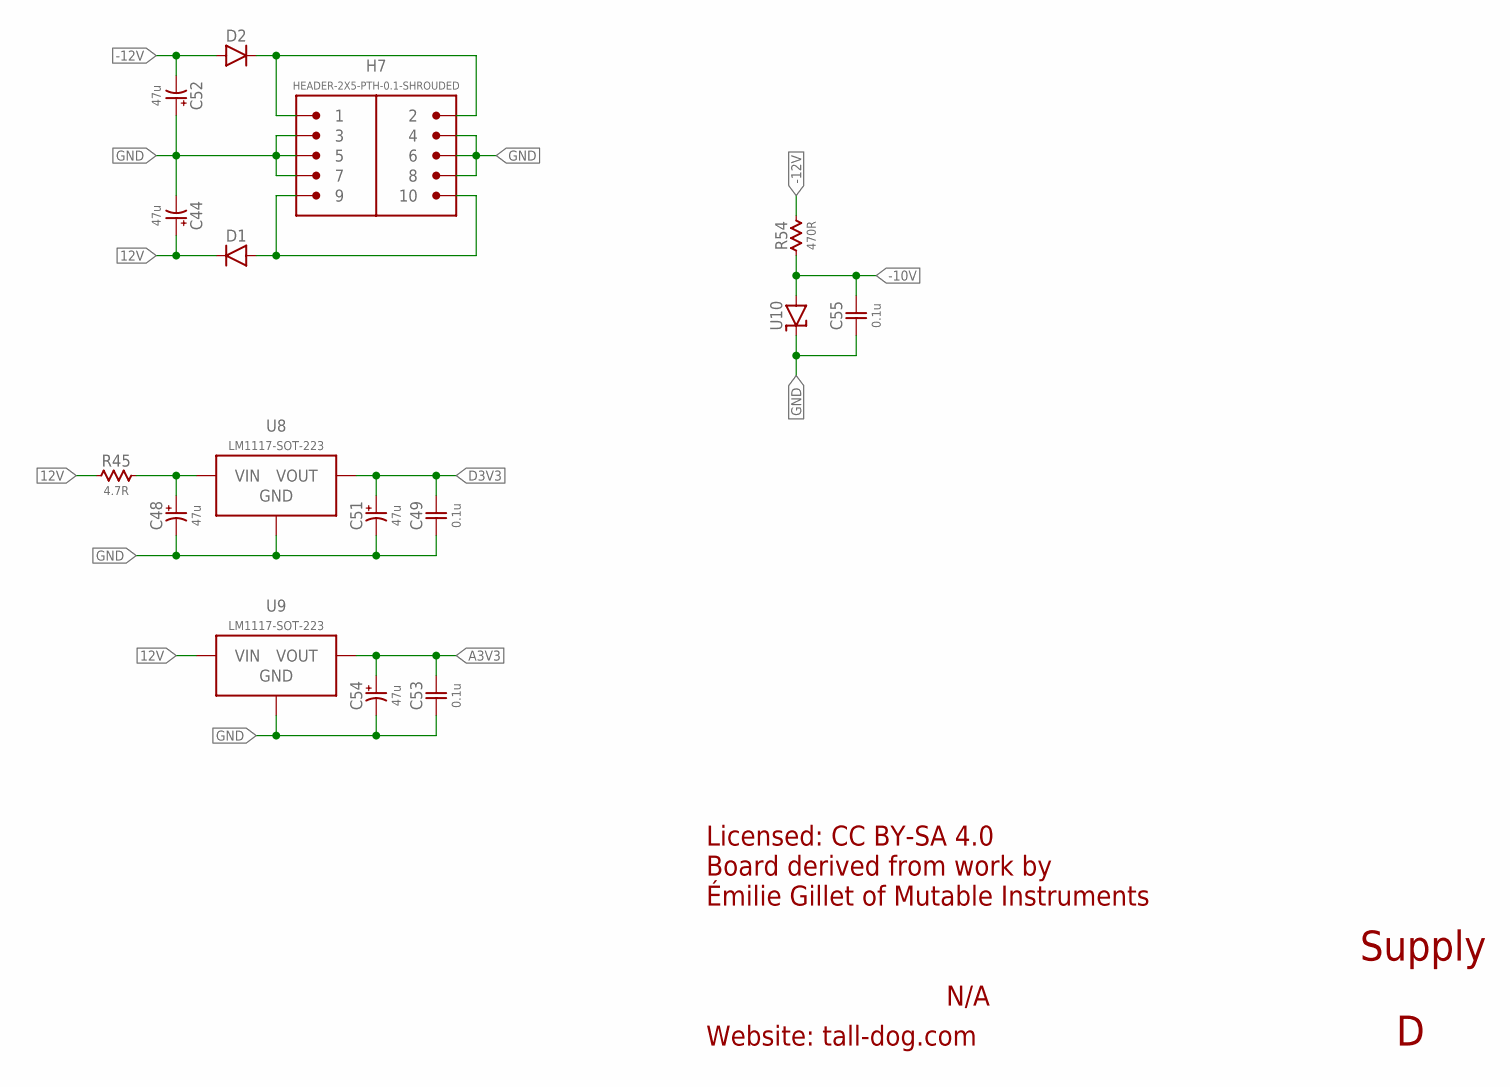
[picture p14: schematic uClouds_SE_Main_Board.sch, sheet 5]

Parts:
C44, C48, C51, C52, C54: 47u; ELECTRO-SMD-6.6MM
C49, C53, C55: 0.1u; 0603-NP
D1, D2: DIODE-SOD123; SOD-123
H7: HEADER-2X5-PTH-0.1-SHROUDED; PTH-0.1-2X5-SHROUDED
R45: 4.7R; 1206-NP
R54: 470R; 0603-NP
U8, U9: LM1117-SOT-223; SOT-223
U10: ZENER-SOT-23; SOT-23

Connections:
12V: C44.A (POS), D1.C, R45.1, U9.3 (VIN); also elsewhere on the board
-10V: C55.2, R54.1, U10.2 (A); also elsewhere on the board
-12V: C52.C (NEG), D2.A, R54.2; also elsewhere on the board
A3V3: C53.2, C54.A (POS), U9.2 (VOUT), U9.4 (VOUT); also elsewhere on the board
D3V3: C49.2, C51.A (POS), U8.2 (VOUT), U8.4 (VOUT); also elsewhere on the board
GND: C44.C (NEG), C48.C (NEG), C49.1, C51.C (NEG), C52.A (POS), C53.1, C54.C (NEG), C55.1, H7.3, H7.4, H7.5, H7.6, H7.7, H7.8, U8.1 (GND), U9.1 (GND), U10.1 (C); also elsewhere on the board
unnamed: C48.A (POS), R45.2, U8.3 (VIN)
unnamed: D2.C, H7.1, H7.2
unnamed: D1.A, H7.9, H7.10

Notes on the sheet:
Licensed: CC BY-SA 4.0 Board derived from work by Émilie Gillet of Mutable Instruments
Website: tall-dog.com
N/A
Supply

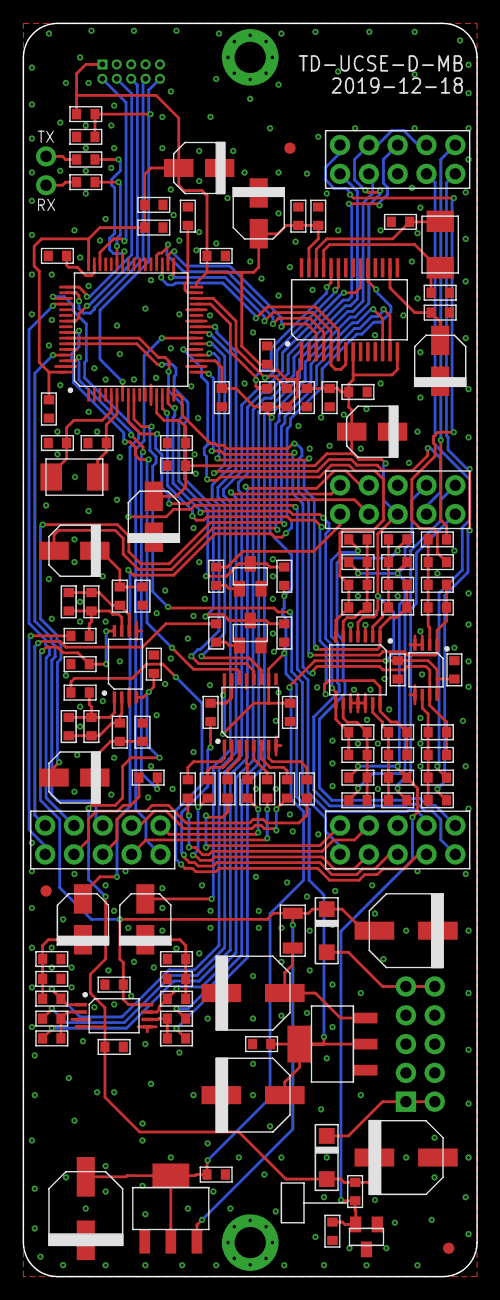
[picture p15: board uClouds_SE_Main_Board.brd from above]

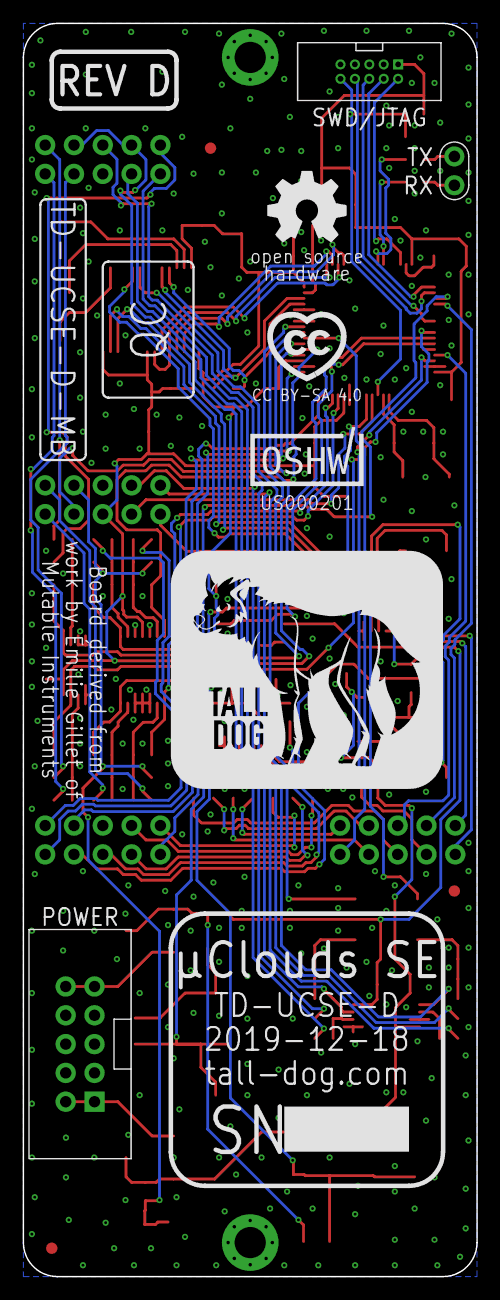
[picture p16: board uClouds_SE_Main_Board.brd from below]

Board: 2 copper layers, 40.0 x 110.5 mm, 145 parts (15 on the bottom side), 107 nets.

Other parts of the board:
U$1, U$3, U$6: FIDUCIAL
U$2: LOGO-OSHW
U$4: LOGO-OSH
U$5: LOGO-CC
U$7: LOGO-REV
U$8: LOGO-SN
U$9: LOGO-TD
U$10: LOGO-PN
U$11: LOGO-QC

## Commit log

2018-11-17 initial commit, revision C production
    [uClouds_SE_Assembly_Spacer.stl, uClouds_SE_Assembly_Template.brd, uClouds_SE_Button_Shim.stl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]
2019-07-12 assembly process updates
    [uClouds_SE_Assembly_Spacer.stl, uClouds_SE_Button_Shim.brd, uClouds_SE_Button_Shim.stl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]
2019-12-14 Updates for Revision D
    [uClouds_SE_Assembly_Template.brd, uClouds_SE_Button_Shim.brd, uClouds_SE_Control_Board.brd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]
2019-12-18 Cleanup and silkscreen artwork updates
    [uClouds_SE_Control_Board.brd, uClouds_SE_Control_Board.sch, uClouds_SE_Main_Board.brd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]
2021-03-23 Revision D
    [uClouds_SE_Assembly_Cap.stl, uClouds_SE_Assembly_Spacer.stl, uClouds_SE_Assembly_Template.brd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]
